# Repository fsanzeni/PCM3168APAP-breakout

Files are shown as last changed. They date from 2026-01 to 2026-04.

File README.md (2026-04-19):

# PCM3168APAP Breakout Board

A breakout board for the Texas Instruments PCM3168APAP audio codec, featuring 6 analog inputs and 8 analog outputs with high-quality buffering and filtering circuitry.
| PCB Front | PCB Back |
|---|---|
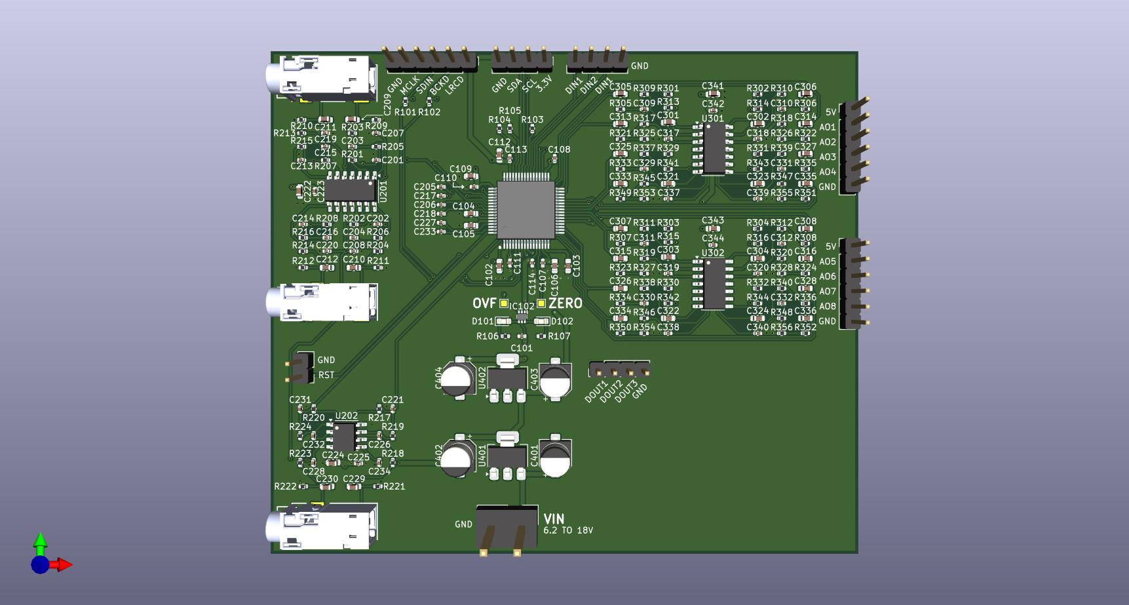
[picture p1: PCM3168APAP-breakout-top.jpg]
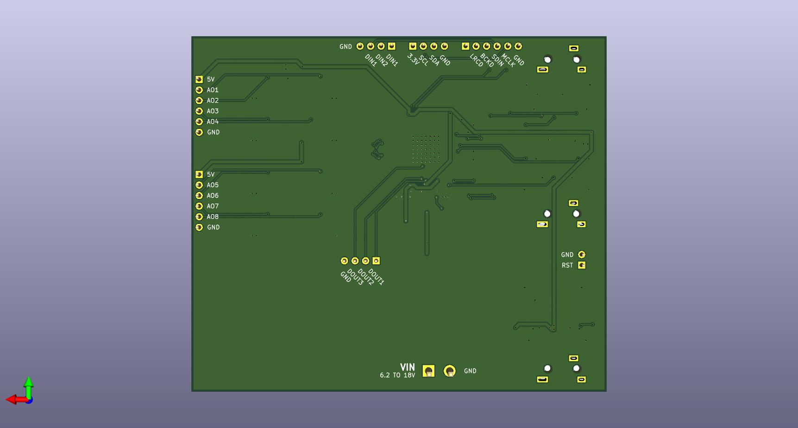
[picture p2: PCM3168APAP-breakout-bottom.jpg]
|  |  |

## Overview

This evaluation board is based on the [TI TIDA-00609](https://www.ti.com/tool/TIDA-00609) reference design and provides a complete interface to the [PCM3168APAP](https://www.ti.com/product/PCM3168A/part-details/PCM3168APAP) - a 24-bit, 96kHz/192kHz, 6-in/8-out audio codec. The board includes analog input buffering with anti-aliasing filters, differential-to-single-ended output conversion, and integrated power regulation (via LDOs for 5v and 3.3v).

## Features

### Audio Codec
- **ADC**: 6-channel, 24-bit delta-sigma ADC with 107 dB dynamic range (differential), 104 dB (single-ended)
- **DAC**: 8-channel, 24-bit delta-sigma DAC with 112 dB dynamic range and differential 8V peak-to-peak outputs
- Sampling rates: 8 kHz to 192 kHz (ADC up to 96 kHz, DAC up to 192 kHz)
- Supports I²S, left-justified, right-justified, DSP, and TDM audio formats

### Analog Signal Path

#### Inputs (6 channels)
- 3.5mm TRS jack connectors for each stereo input pair
- Buffer and anti-aliasing low-pass filter based on [OPA4134](https://www.ti.com/product/OPA4134)/[OPA2134](https://www.ti.com/product/OPA2134) op-amps
- Configured for 2V RMS input, 0.5x gain, -3dB at 48 kHz 
- Output: 1V RMS to ADC
- Common-mode reference voltage (VCOMAD) generation

#### Outputs (8 channels)
- Two 6-pin headers providing 4 channels each
- Post-LPF and differential-to-single-ended conversion using OPA4134 op-amps
- Configured for 4V peak-to-peak DAC output, 0.747x gain, -3dB at 53 kHz
- Output: 2V RMS single-ended

### Digital Interface
- **I²S/Audio** (6-pin header): MCLK, BCK_ADC, LRCK_ADC, BCK_DAC, LRCK_DAC, and ground
- **I²C** (4-pin header): SDA, SCL, 3.3V, and ground
- **Digital Input** (4-pin header): DIN2, DIN3, SDIN (DIN1), and ground
- **Digital Output** (4-pin header): DOUT1, DOUT2, DOUT3, and ground
- **Reset** (2-pin header): Active-low reset with buffer IC ([SN74LVC2G34](https://www.ti.com/product/SN74LVC2G34))

### Configuration
- I²C mode (MODE pin tied to GND)
- I²C device address: 0x88
- Test points for ZERO and OVERFLOW flags
- Status LEDs: Green (ZERO), Yellow (OVERFLOW)

### Power Supply
- Input voltage: 6.2V to 18V
- Dual linear regulators (AMS1117):
  - 5V output for analog circuitry
  - 3.3V output for digital logic
- Comprehensive decoupling throughout

## BOM Highlights

### Key Components
- **IC101**: PCM3168APAP (HTQFP-64 package)
- **IC102**: SN74LVC2G34DRLR (dual buffer for reset/LEDs)
- **U201-U202, U301-U302**: OPA4134UA/OPA2134 (audio op-amps)
- **U401-U402**: AMS1117-5.0 and AMS1117-3.3 (linear regulators)

### Connectors
- J101: 6-pin I²S header
- J102: 4-pin I²C header
- J103-J104: 4-pin DIN/DOUT headers
- J201-J203: 3.5mm TRS analog input jacks
- J301-J302: 6-pin analog output headers
- J401: 2-pin power input

## Usage Notes

- Ensure proper power supply voltage range (6.2V minimum to avoid dropout on regulators) 
- The board is configured for I²C control by default
- All analog inputs accept balanced TRS connections or can be used with unbalanced sources
- Output headers provide differential pairs that have been converted to single-ended signals 

## License

[MIT License](./LICENSE)

## Revision History

- **v0.1** (2026-01-13): Initial release

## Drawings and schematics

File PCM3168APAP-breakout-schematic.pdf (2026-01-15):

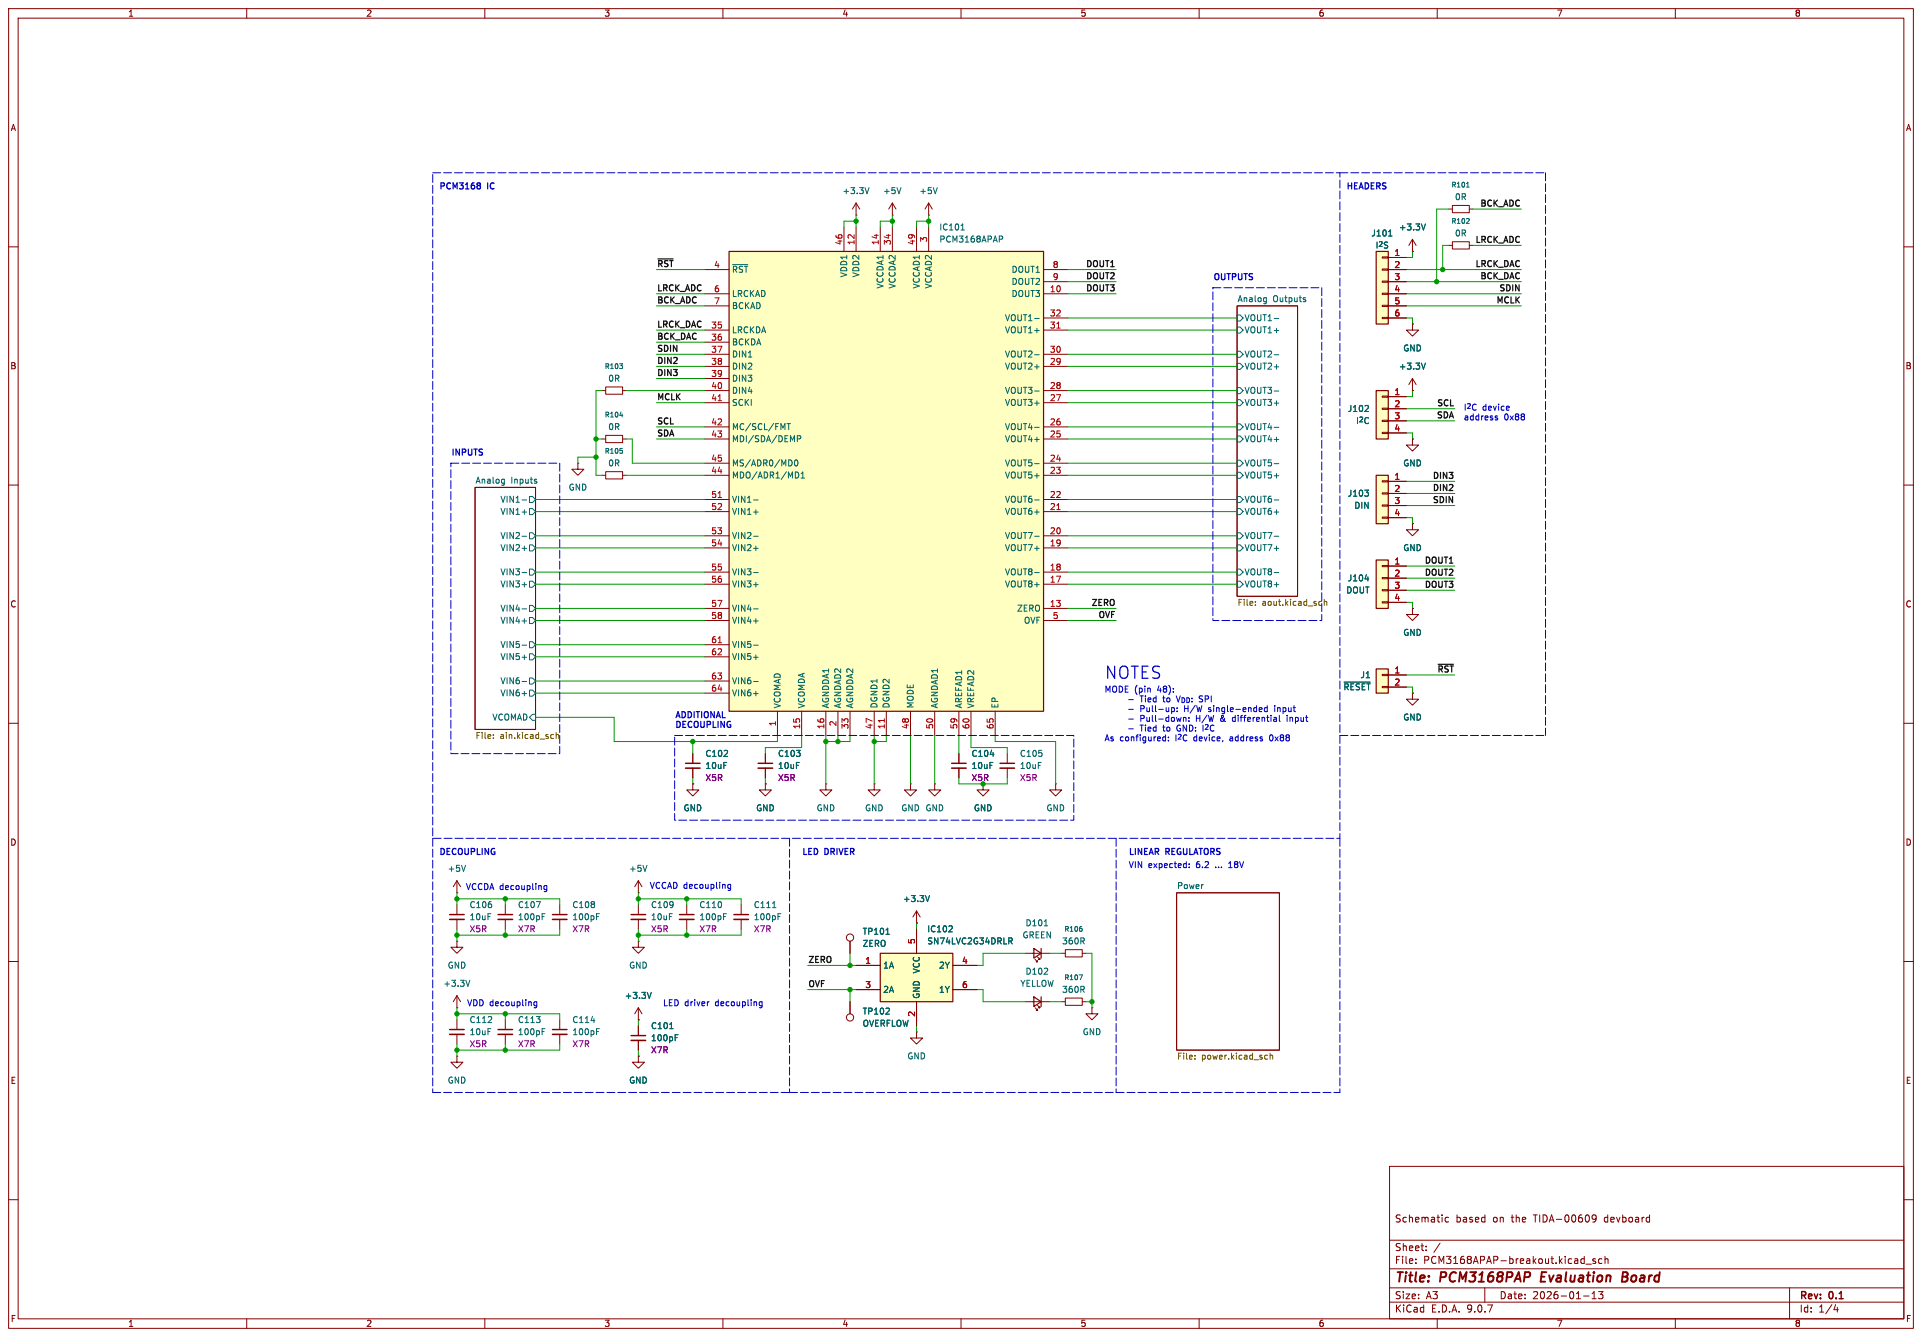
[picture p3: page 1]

VOUT1+ VOUT1- VOUT2+ VOUT2- VOUT3+ VOUT3- VOUT4+ VOUT4- VOUT5+ VOUT5- VOUT6+ VOUT6- VOUT7+ VOUT7- VOUT8+ VOUT8- Analog Outputs File: aout.kicad_sch Power File: power.kicad_sch GND GND

SDIN
VIN1+ VIN1- VIN2+ VIN2- VIN3+ VIN3- VIN4+ VIN4- VIN5+ VIN5- VIN6+ VIN6- Analog Inputs File: ain.kicad_sch

Id: 1/4 Title: PCM3168PAP Evaluation Board

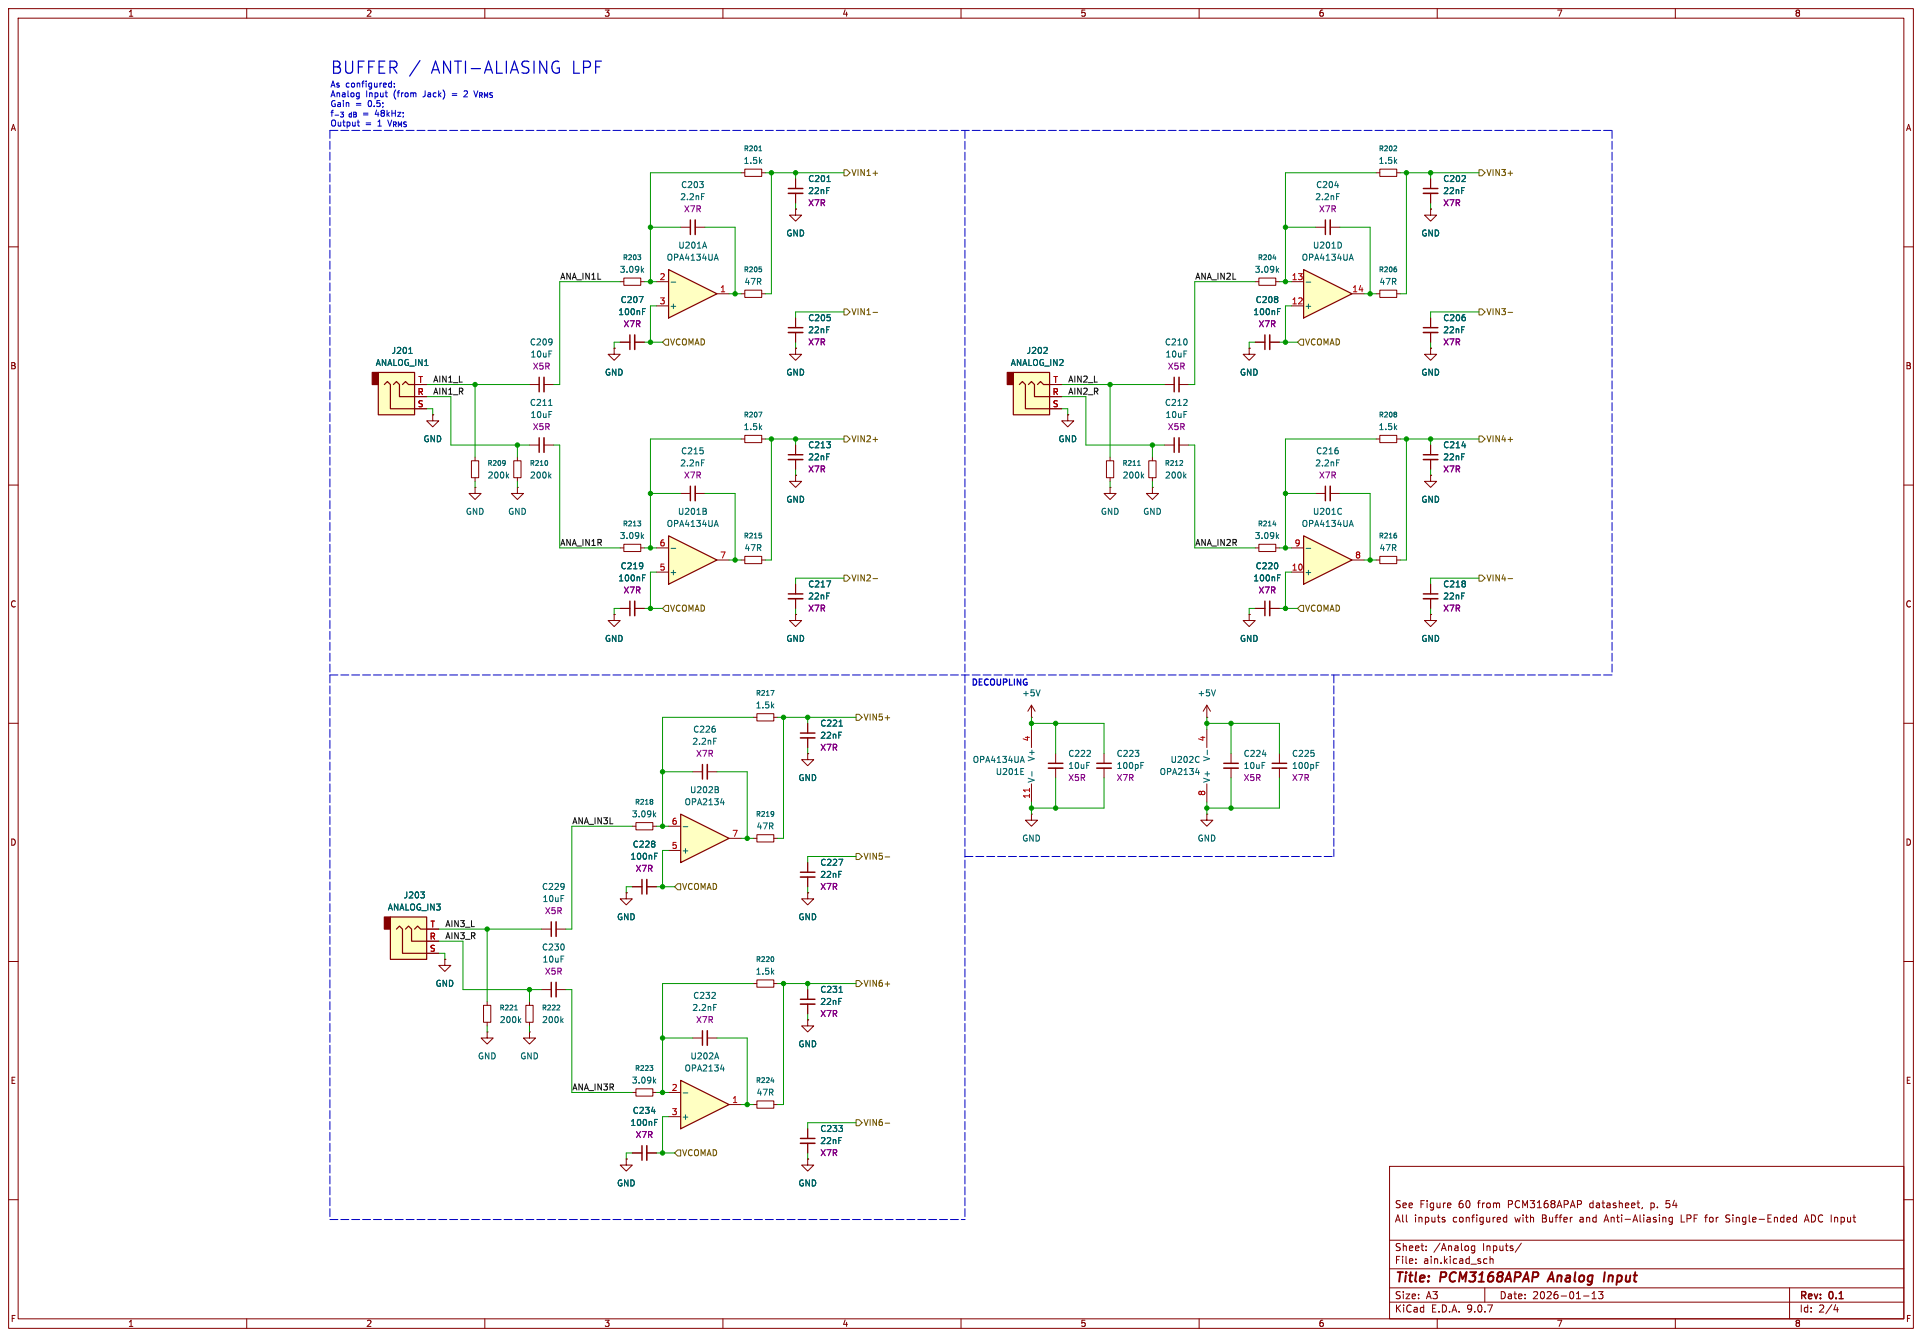
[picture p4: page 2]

BUFFER / ANTI-ALIASING LPF
AIN1_L As configured:
Analog Input (from Jack) = 2 V_{RMS} Gain = 0.5;
1 U201A OPA4134UA C219

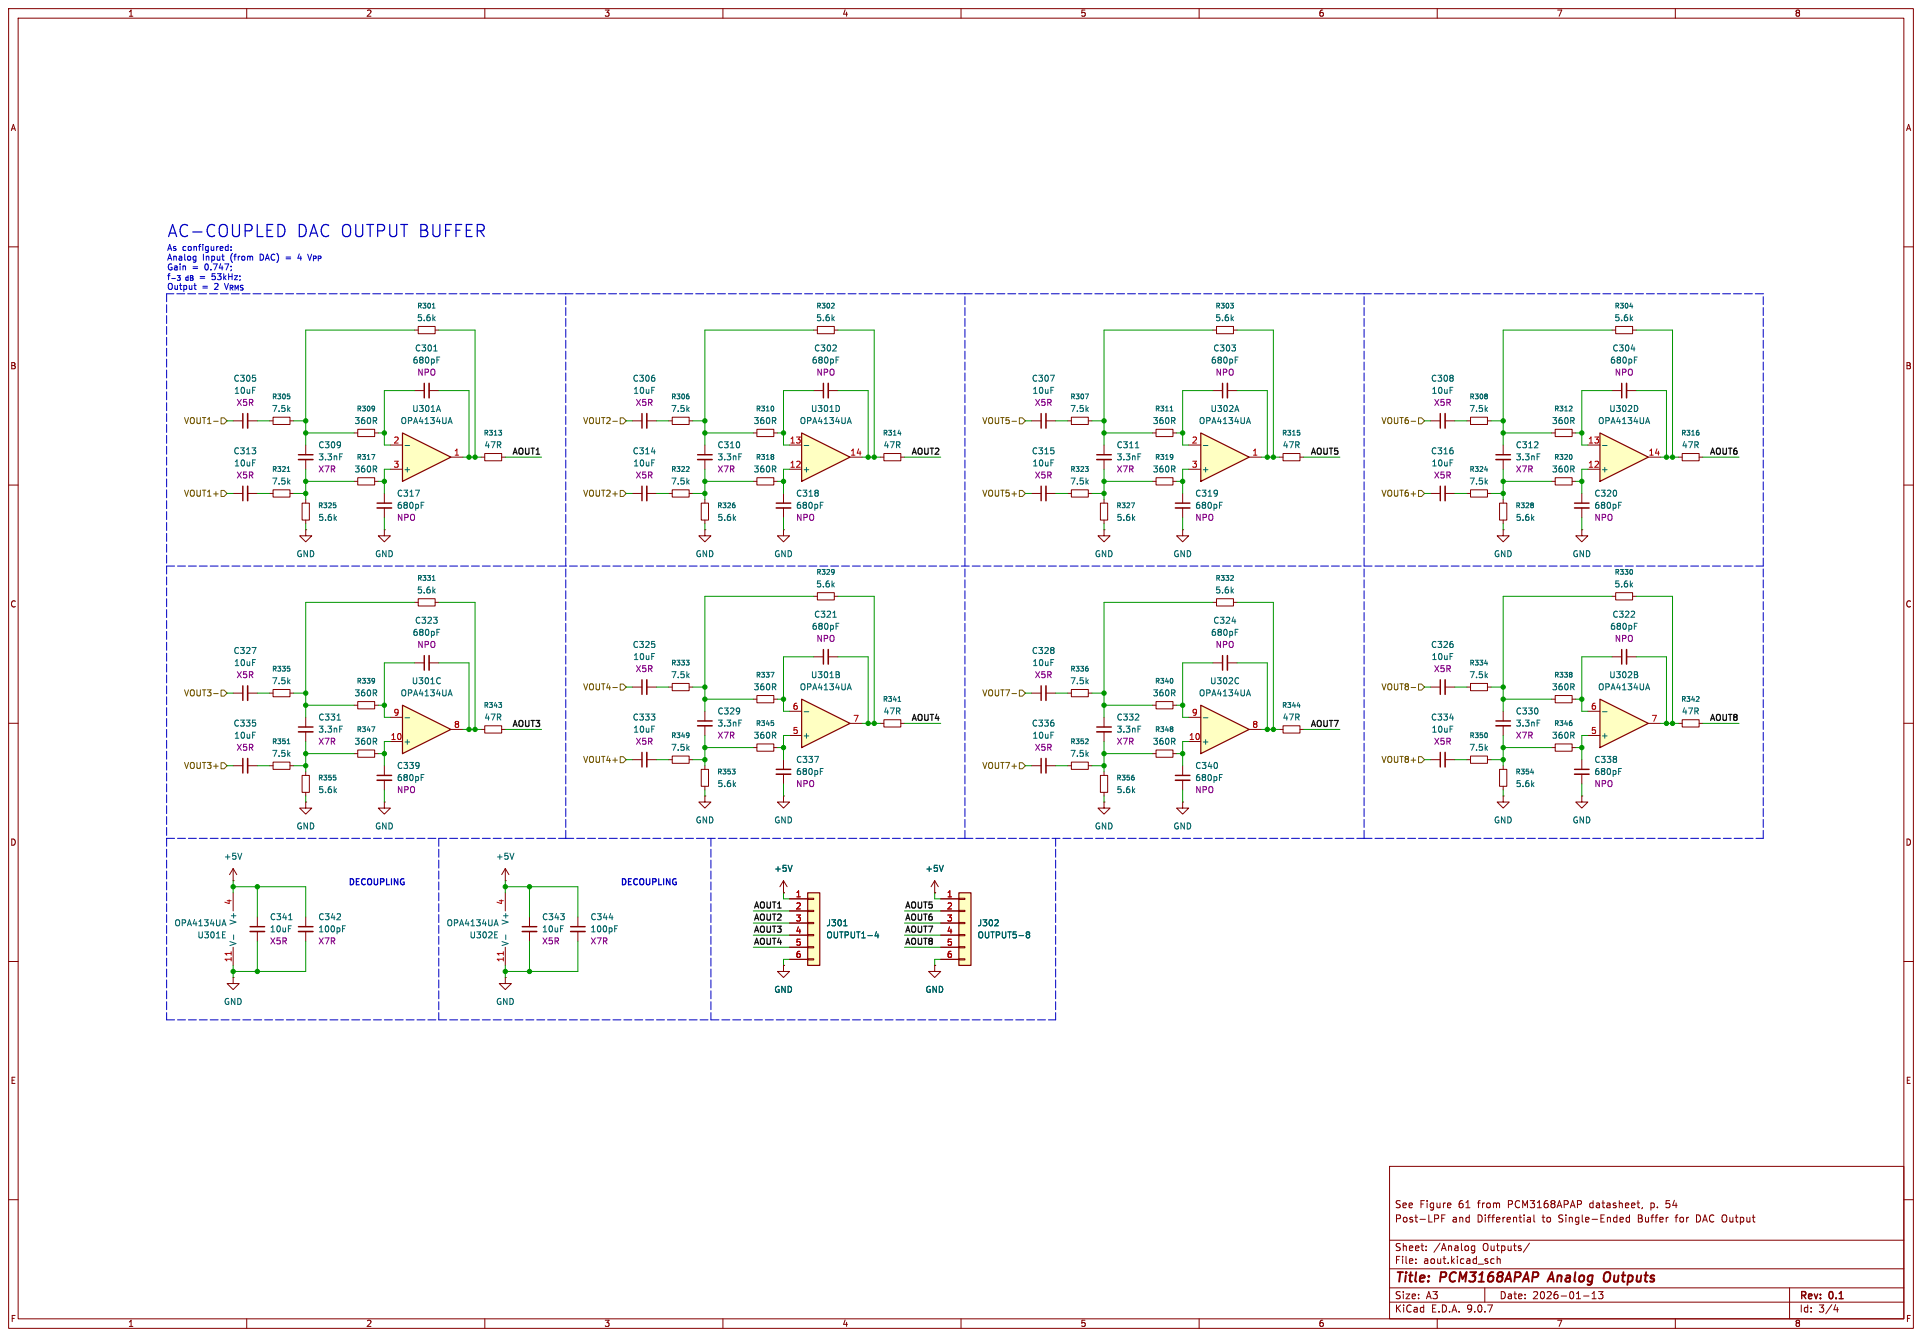
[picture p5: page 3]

As configured:
Analog Input (from DAC) = 4 V_{PP} Gain = 0.747;

Id: 3/4 Title: PCM3168APAP Analog Outputs

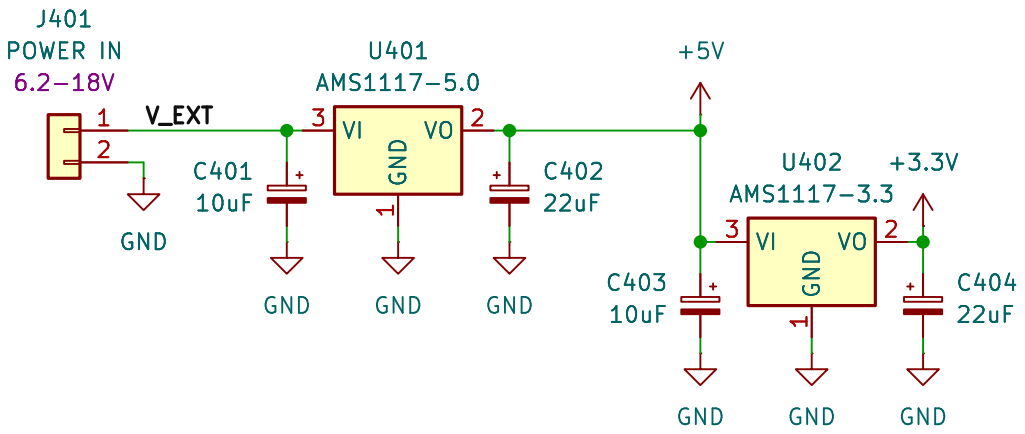
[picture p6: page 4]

Id: 4/4 Title: File: power.kicad_sch Sheet: /Power/

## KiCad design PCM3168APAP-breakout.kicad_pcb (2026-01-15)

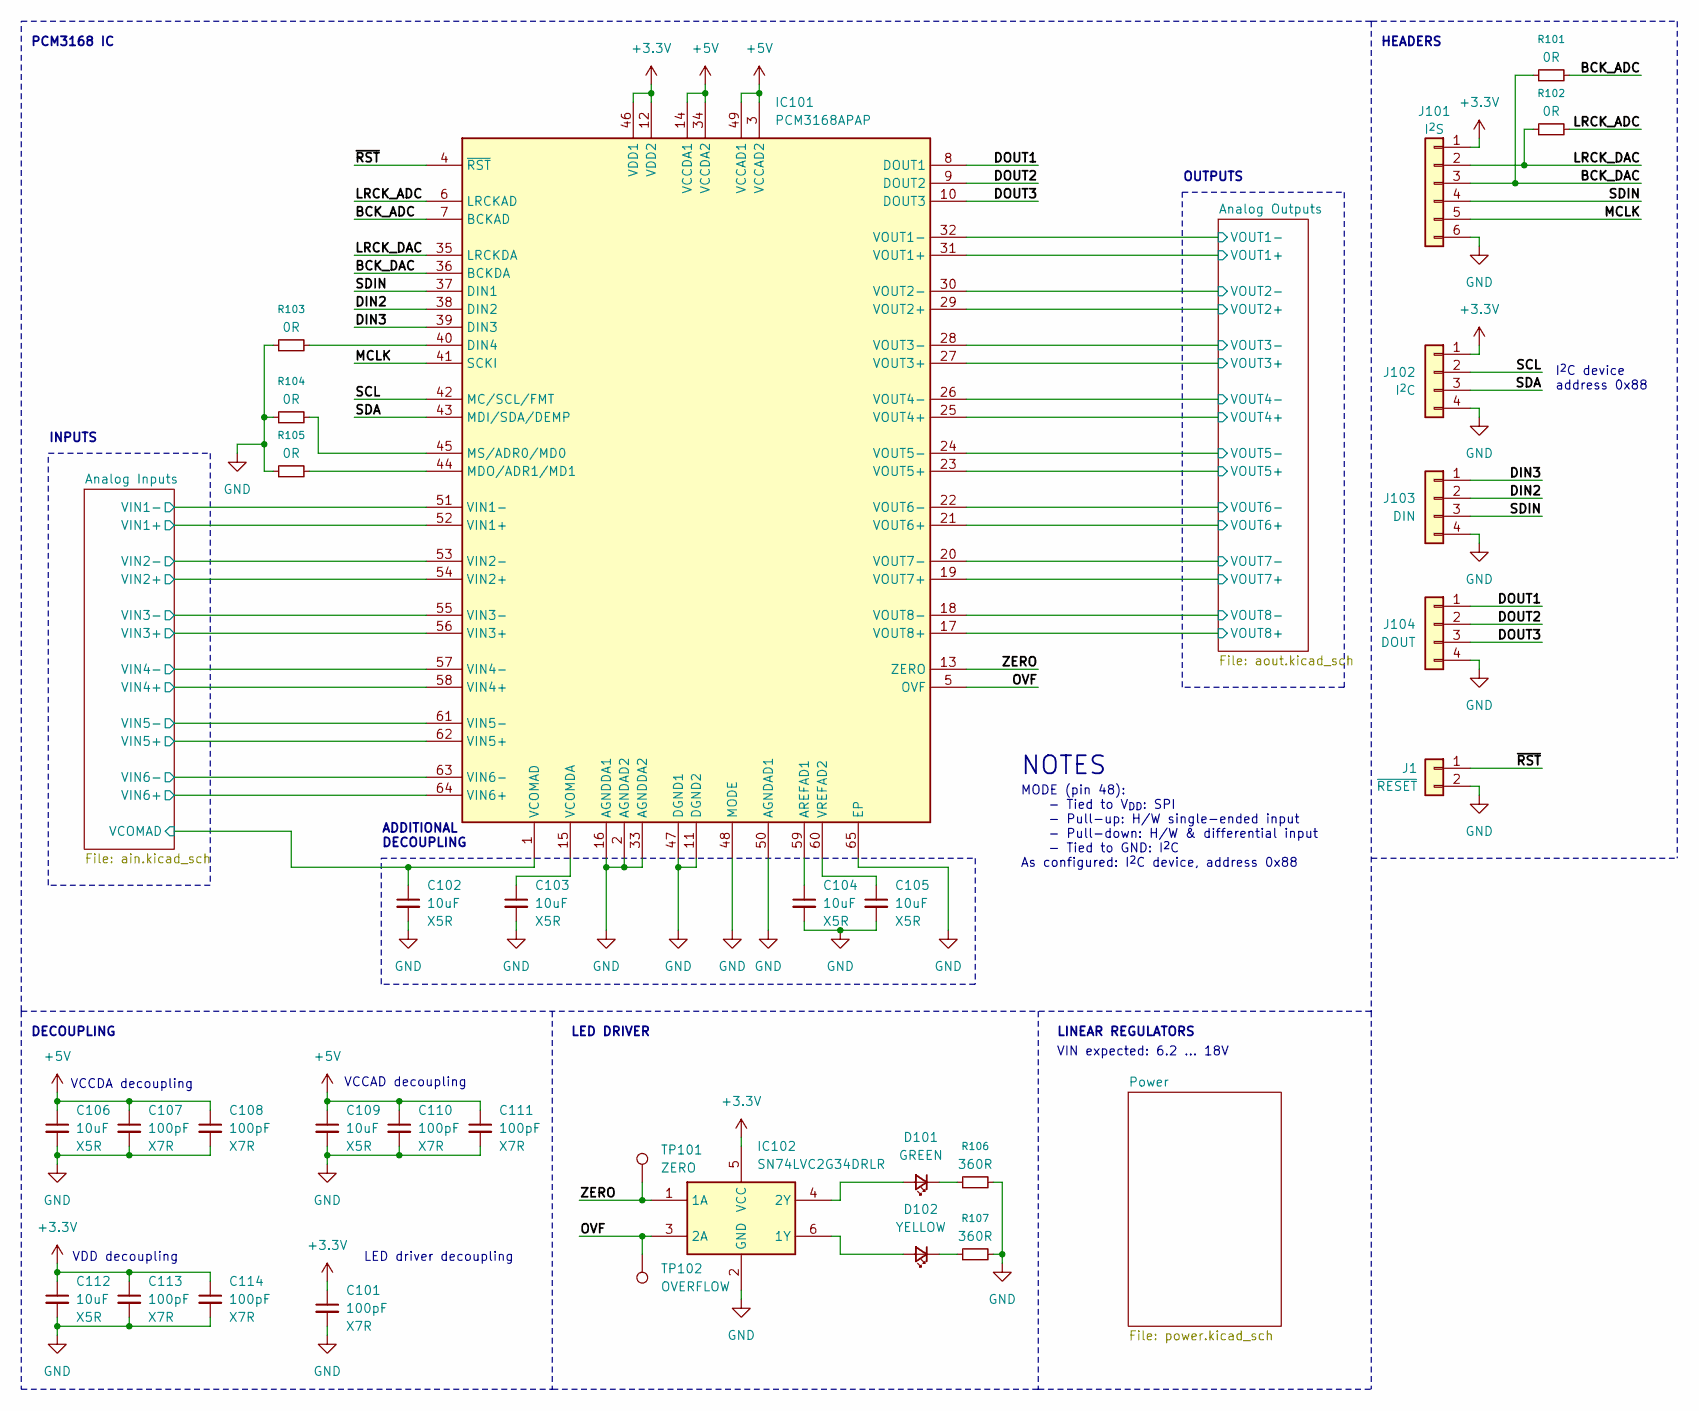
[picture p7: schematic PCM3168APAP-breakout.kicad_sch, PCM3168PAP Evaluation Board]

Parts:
C101, C107, C108, C110, C111, C113, C114: 100pF; C_0402_1005Metric
C102, C103, C104, C105, C106, C109, C112: 10uF; C_0603_1608Metric
D101: GREEN; LED_0603_1608Metric
D102: YELLOW; LED_0603_1608Metric
IC101: PCM3168APAP; QFP50P1200X1200X120-65N; Mouser Part Number 595-PCM3168APAP
IC102: SN74LVC2G34DRLR; SOTFL50P160X60-6N; Mouser Part Number 595-SN74LVC2G34DRLR
J1: ~{RESET}; PinHeader_1x02_P2.54mm_Vertical
J101: I^{2}S; PinHeader_1x06_P2.54mm_Vertical
J102: I^{2}C; PinHeader_1x04_P2.54mm_Vertical
J103: DIN; PinHeader_1x04_P2.54mm_Vertical
J104: DOUT; PinHeader_1x04_P2.54mm_Vertical
R101, R102, R103, R104, R105: 0R; R_0402_1005Metric
R106, R107: 360R; R_0402_1005Metric
TP101: ZERO; TestPoint_Pad_1.0x1.0mm
TP102: OVERFLOW; TestPoint_Pad_1.0x1.0mm

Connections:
+3.3V: C101.1, C112.1, C113.1, C114.1, IC101.12 (VDD2), IC101.46 (VDD1), IC102.5 (VCC), J101.1, J102.1; also elsewhere on the board
+5V: C106.1, C107.1, C108.1, C109.1, C110.1, C111.1, IC101.3 (VCCAD2), IC101.14 (VCCDA1), IC101.34 (VCCDA2), IC101.49 (VCCAD1); also elsewhere on the board
/Analog Inputs/VCOMAD: C102.1, IC101.1 (VCOMAD); also elsewhere on the board
/Analog Inputs/VIN1+: IC101.52 (VIN1+); also elsewhere on the board
/Analog Inputs/VIN1-: IC101.51 (VIN1-); also elsewhere on the board
/Analog Inputs/VIN2+: IC101.54 (VIN2+); also elsewhere on the board
/Analog Inputs/VIN2-: IC101.53 (VIN2-); also elsewhere on the board
/Analog Inputs/VIN3+: IC101.56 (VIN3+); also elsewhere on the board
/Analog Inputs/VIN3-: IC101.55 (VIN3-); also elsewhere on the board
/Analog Inputs/VIN4+: IC101.58 (VIN4+); also elsewhere on the board
/Analog Inputs/VIN4-: IC101.57 (VIN4-); also elsewhere on the board
/Analog Inputs/VIN5+: IC101.62 (VIN5+); also elsewhere on the board
/Analog Inputs/VIN5-: IC101.61 (VIN5-); also elsewhere on the board
/Analog Inputs/VIN6+: IC101.64 (VIN6+); also elsewhere on the board
/Analog Inputs/VIN6-: IC101.63 (VIN6-); also elsewhere on the board
/Analog Outputs/VOUT1+: IC101.31 (VOUT1+); also elsewhere on the board
/Analog Outputs/VOUT1-: IC101.32 (VOUT1-); also elsewhere on the board
/Analog Outputs/VOUT2+: IC101.29 (VOUT2+); also elsewhere on the board
/Analog Outputs/VOUT2-: IC101.30 (VOUT2-); also elsewhere on the board
/Analog Outputs/VOUT3+: IC101.27 (VOUT3+); also elsewhere on the board
/Analog Outputs/VOUT3-: IC101.28 (VOUT3-); also elsewhere on the board
/Analog Outputs/VOUT4+: IC101.25 (VOUT4+); also elsewhere on the board
/Analog Outputs/VOUT4-: IC101.26 (VOUT4-); also elsewhere on the board
/Analog Outputs/VOUT5+: IC101.23 (VOUT5+); also elsewhere on the board
/Analog Outputs/VOUT5-: IC101.24 (VOUT5-); also elsewhere on the board
/Analog Outputs/VOUT6+: IC101.21 (VOUT6+); also elsewhere on the board
/Analog Outputs/VOUT6-: IC101.22 (VOUT6-); also elsewhere on the board
/Analog Outputs/VOUT7+: IC101.19 (VOUT7+); also elsewhere on the board
/Analog Outputs/VOUT7-: IC101.20 (VOUT7-); also elsewhere on the board
/Analog Outputs/VOUT8+: IC101.17 (VOUT8+); also elsewhere on the board
/Analog Outputs/VOUT8-: IC101.18 (VOUT8-); also elsewhere on the board
/BCK_ADC: IC101.7 (BCKAD), R101.2
/BCK_DAC: IC101.36 (BCKDA), J101.3, R101.1
/DIN2: IC101.38 (DIN2), J103.2
/DIN3: IC101.39 (DIN3), J103.1
/DOUT1: IC101.8 (DOUT1), J104.1
/DOUT2: IC101.9 (DOUT2), J104.2
/DOUT3: IC101.10 (DOUT3), J104.3
/LRCK_ADC: IC101.6 (LRCKAD), R102.2
/LRCK_DAC: IC101.35 (LRCKDA), J101.2, R102.1
/MCLK: IC101.41 (SCKI), J101.5
/OVF: IC101.5 (OVF), IC102.3 (2A), TP102.1
/SCL: IC101.42 (MC/SCL/FMT), J102.2
/SDA: IC101.43 (MDI/SDA/DEMP), J102.3
/SDIN: IC101.37 (DIN1), J101.4, J103.3
/ZERO: IC101.13 (ZERO), IC102.1 (1A), TP101.1
/~RST: IC101.4 (~RST), J1.1
GND: C101.2, C102.2, C103.2, C104.2, C105.2, C106.2, C107.2, C108.2, C109.2, C110.2, C111.2, C112.2, C113.2, C114.2, IC101.2 (AGNDAD2), IC101.11 (DGND2), IC101.16 (AGNDDA1), IC101.33 (AGNDDA2), IC101.47 (DGND1), IC101.48 (MODE), IC101.50 (AGNDAD1), IC101.65 (EP), IC102.2 (GND), J1.2, J101.6, J102.4, J103.4, J104.4, R103.1, R104.1, R105.1, R106.2, R107.2; also elsewhere on the board
unnamed: D101.2 (A), IC102.4 (2Y)
unnamed: D101.1 (K), R106.1
unnamed: D102.2 (A), IC102.6 (1Y)
unnamed: D102.1 (K), R107.1
unnamed: C104.1, IC101.59 (AREFAD1)
unnamed: IC101.40 (DIN4), R103.2
unnamed: IC101.44 (MDO/ADR1/MD1), R105.2
unnamed: IC101.45 (MS/ADR0/MD0), R104.2
unnamed: C103.1, IC101.15 (VCOMDA)
unnamed: C105.1, IC101.60 (VREFAD2)

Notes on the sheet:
LED DRIVER
I^{2}C device address 0x88
DECOUPLING
PCM3168 IC
VCCAD decoupling
ADDITIONAL DECOUPLING
OUTPUTS
VDD decoupling
VCCDA decoupling
VIN expected: 6.2 ... 18V
LED driver decoupling
INPUTS
MODE (pin 48): - Tied to V_{DD}: SPI - Pull-up: H/W single-ended input - Pull-down: H/W & differential input - Tied to GND: I^{2}C As configured: I^{2}C device, address 0x88
NOTES
HEADERS
LINEAR REGULATORS

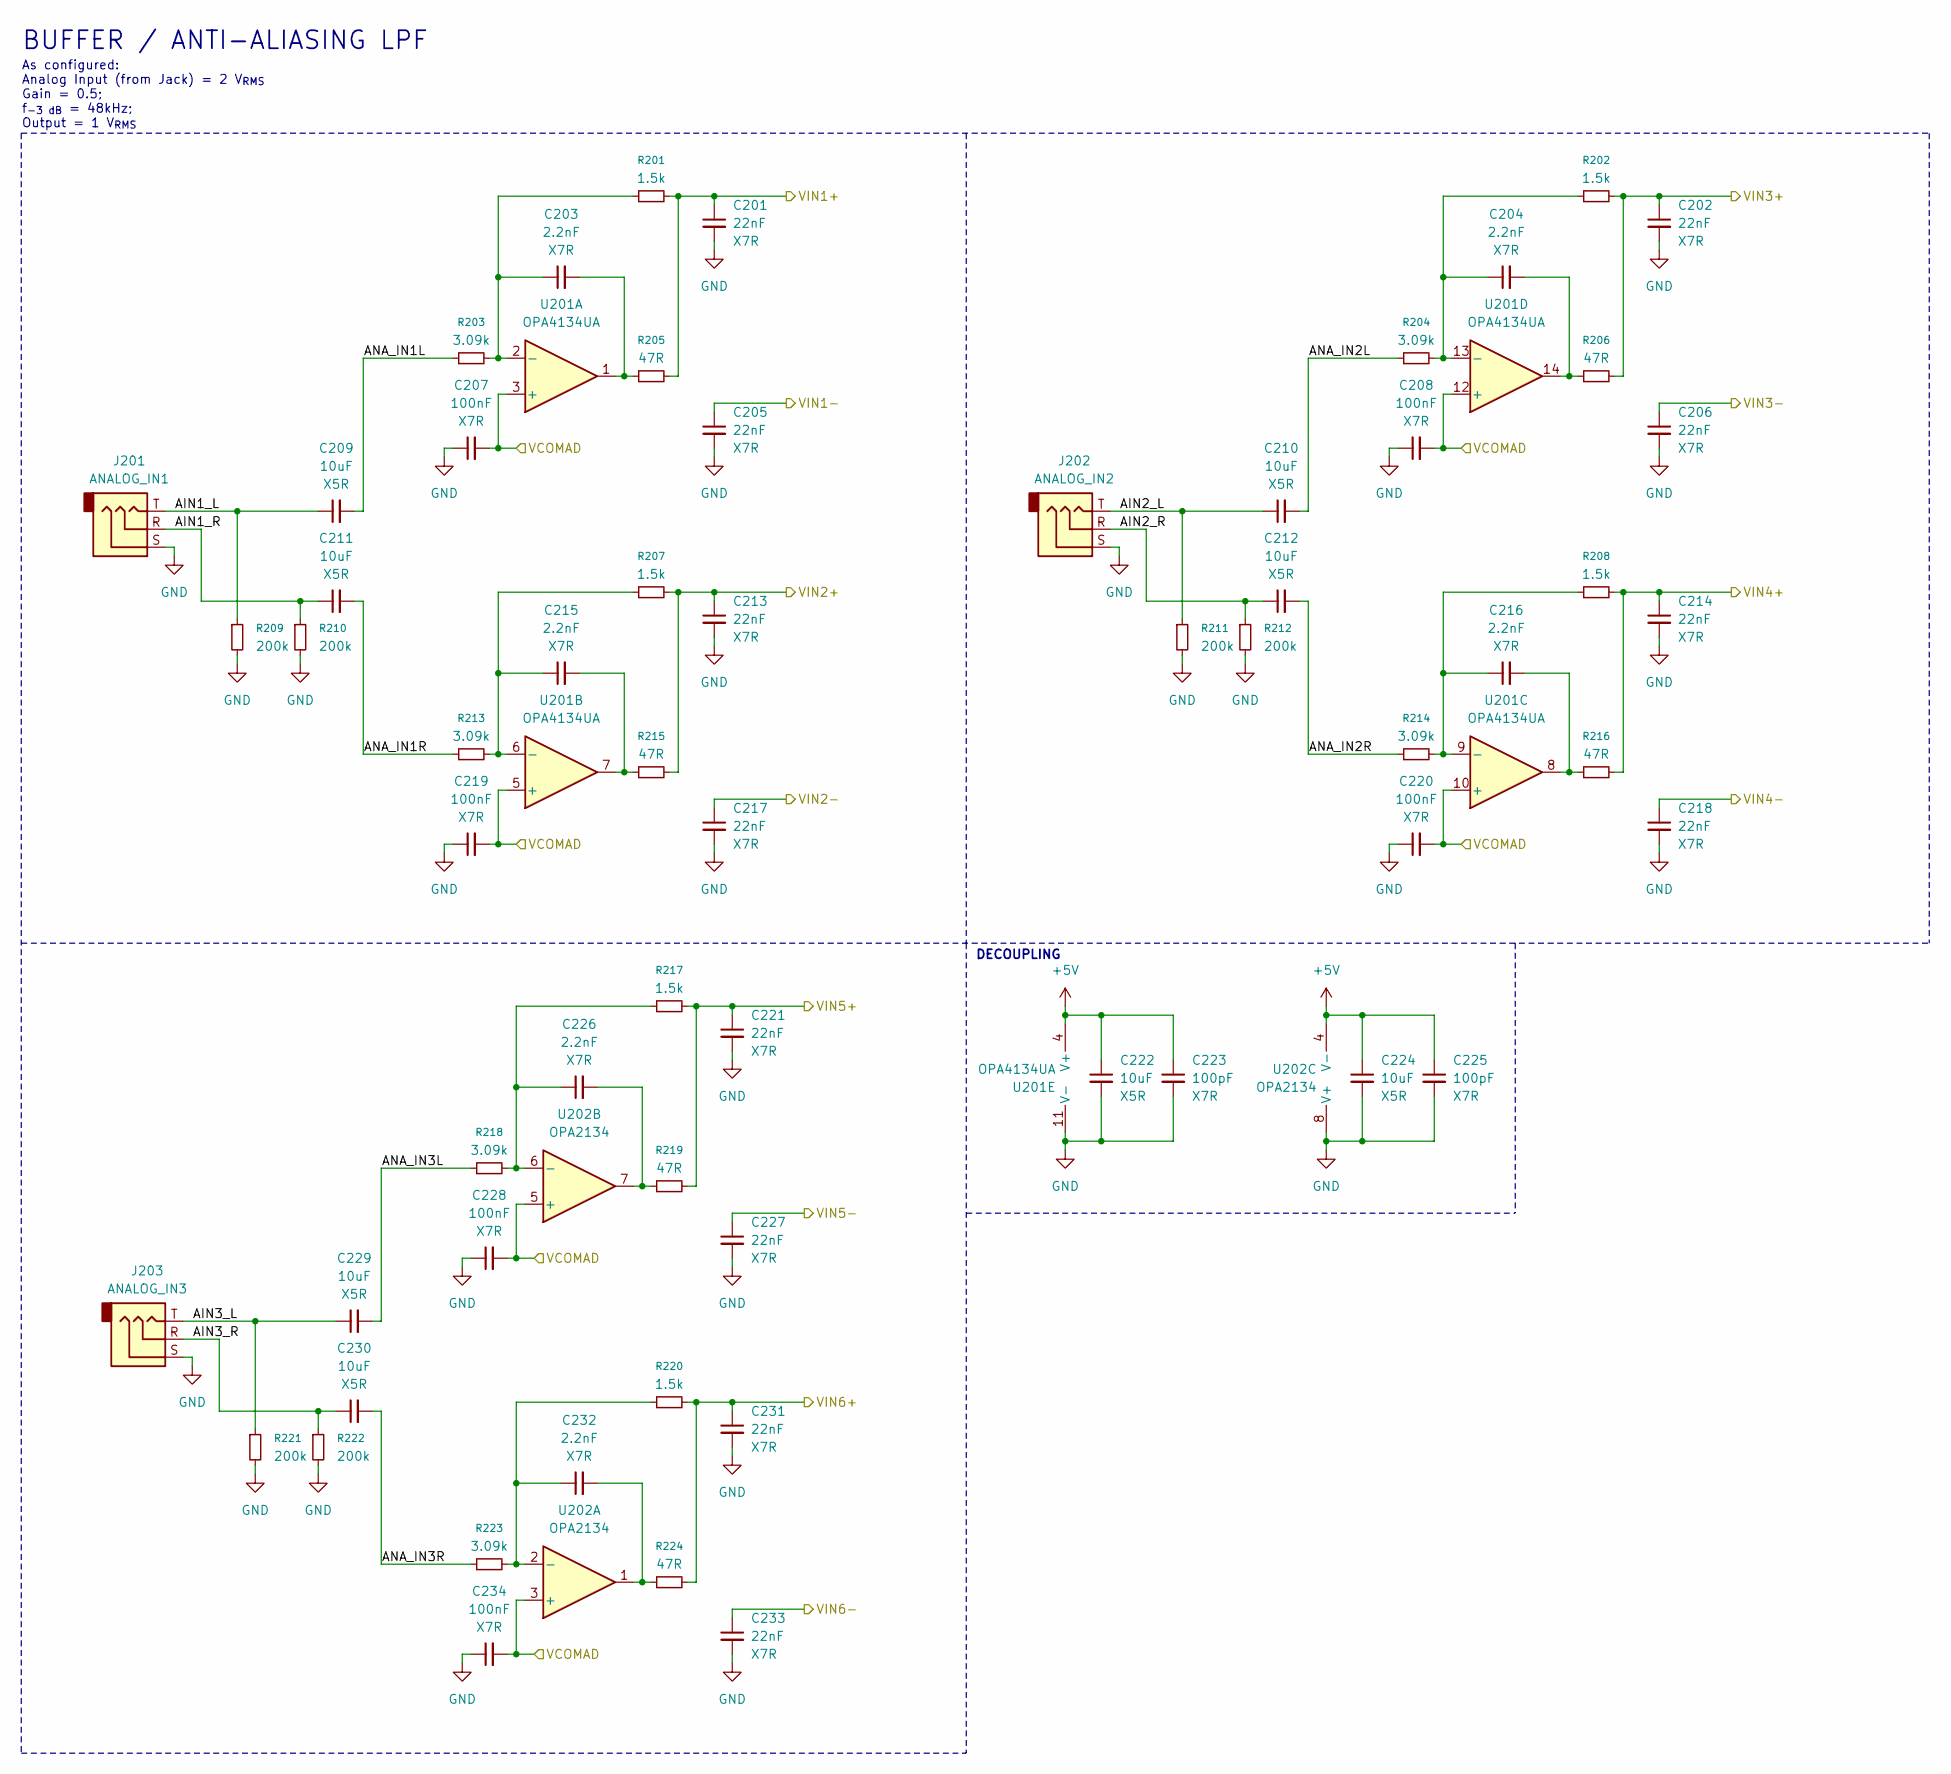
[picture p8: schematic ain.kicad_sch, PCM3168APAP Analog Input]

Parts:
C201, C202, C205, C206, C213, C214, C217, C218, C221, C227, C231, C233: 22nF; C_0402_1005Metric
C203, C204, C215, C216, C226, C232: 2.2nF; C_0402_1005Metric
C207, C208, C219, C220, C228, C234: 100nF; C_0402_1005Metric
C209, C210, C211, C212, C222, C224, C229, C230: 10uF; C_0603_1608Metric
C223, C225: 100pF; C_0402_1005Metric
J201: ANALOG_IN1; SJ335083ATR
J202: ANALOG_IN2; SJ335083ATR
J203: ANALOG_IN3; SJ335083ATR
R201, R202, R207, R208, R217, R220: 1.5k; R_0402_1005Metric
R203, R204, R213, R214, R218, R223: 3.09k; R_0402_1005Metric
R205, R206, R215, R216, R219, R224: 47R; R_0402_1005Metric
R209, R210, R211, R212, R221, R222: 200k; R_0402_1005Metric
U201: OPA4134UA; SOIC-14_3.9x8.7mm_P1.27mm
U202: OPA2134; SOIC-8_3.9x4.9mm_P1.27mm

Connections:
+5V: C222.1, C223.1, C224.1, C225.1, U201.4 (V+), U202.4 (V-); also elsewhere on the board
/Analog Inputs/AIN1_L: C209.1, J201.T, R209.1
/Analog Inputs/AIN1_R: C211.1, J201.R, R210.1
/Analog Inputs/AIN2_L: C210.1, J202.T, R211.1
/Analog Inputs/AIN2_R: C212.1, J202.R, R212.1
/Analog Inputs/AIN3_L: C229.1, J203.T, R221.1
/Analog Inputs/AIN3_R: C230.1, J203.R, R222.1
/Analog Inputs/ANA_IN1L: C209.2, R203.1
/Analog Inputs/ANA_IN1R: C211.2, R213.1
/Analog Inputs/ANA_IN2L: C210.2, R204.1
/Analog Inputs/ANA_IN2R: C212.2, R214.1
/Analog Inputs/ANA_IN3L: C229.2, R218.1
/Analog Inputs/ANA_IN3R: C230.2, R223.1
/Analog Inputs/VCOMAD: C207.2, C208.2, C219.2, C220.2, C228.2, C234.2, U201.3 (+), U201.5 (+), U201.10 (+), U201.12 (+), U202.3 (+), U202.5 (+); also elsewhere on the board
/Analog Inputs/VIN1+: C201.1, R201.2, R205.2; also elsewhere on the board
/Analog Inputs/VIN1-: C205.1; also elsewhere on the board
/Analog Inputs/VIN2+: C213.1, R207.2, R215.2; also elsewhere on the board
/Analog Inputs/VIN2-: C217.1; also elsewhere on the board
/Analog Inputs/VIN3+: C202.1, R202.2, R206.2; also elsewhere on the board
/Analog Inputs/VIN3-: C206.1; also elsewhere on the board
/Analog Inputs/VIN4+: C214.1, R208.2, R216.2; also elsewhere on the board
/Analog Inputs/VIN4-: C218.1; also elsewhere on the board
/Analog Inputs/VIN5+: C221.1, R217.2, R219.2; also elsewhere on the board
/Analog Inputs/VIN5-: C227.1; also elsewhere on the board
/Analog Inputs/VIN6+: C231.1, R220.2, R224.2; also elsewhere on the board
/Analog Inputs/VIN6-: C233.1; also elsewhere on the board
GND: C201.2, C202.2, C205.2, C206.2, C207.1, C208.1, C213.2, C214.2, C217.2, C218.2, C219.1, C220.1, C221.2, C222.2, C223.2, C224.2, C225.2, C227.2, C228.1, C231.2, C233.2, C234.1, J201.S, J202.S, J203.S, R209.2, R210.2, R211.2, R212.2, R221.2, R222.2, U201.11 (V-), U202.8 (V+); also elsewhere on the board
unnamed: C203.2, R205.1, U201.1
unnamed: C204.2, R206.1, U201.14
unnamed: C215.2, R215.1, U201.7
unnamed: C216.2, R216.1, U201.8
unnamed: C226.2, R219.1, U202.7
unnamed: C232.2, R224.1, U202.1
unnamed: C203.1, R201.1, R203.2, U201.2 (-)
unnamed: C215.1, R207.1, R213.2, U201.6 (-)
unnamed: C216.1, R208.1, R214.2, U201.9 (-)
unnamed: C204.1, R202.1, R204.2, U201.13 (-)
unnamed: C232.1, R220.1, R223.2, U202.2 (-)
unnamed: C226.1, R217.1, R218.2, U202.6 (-)

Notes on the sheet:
DECOUPLING
BUFFER / ANTI-ALIASING LPF
As configured: Analog Input (from Jack) = 2 V_{RMS} Gain = 0.5; f_{-3 dB} = 48kHz; Output = 1 V_{RMS}

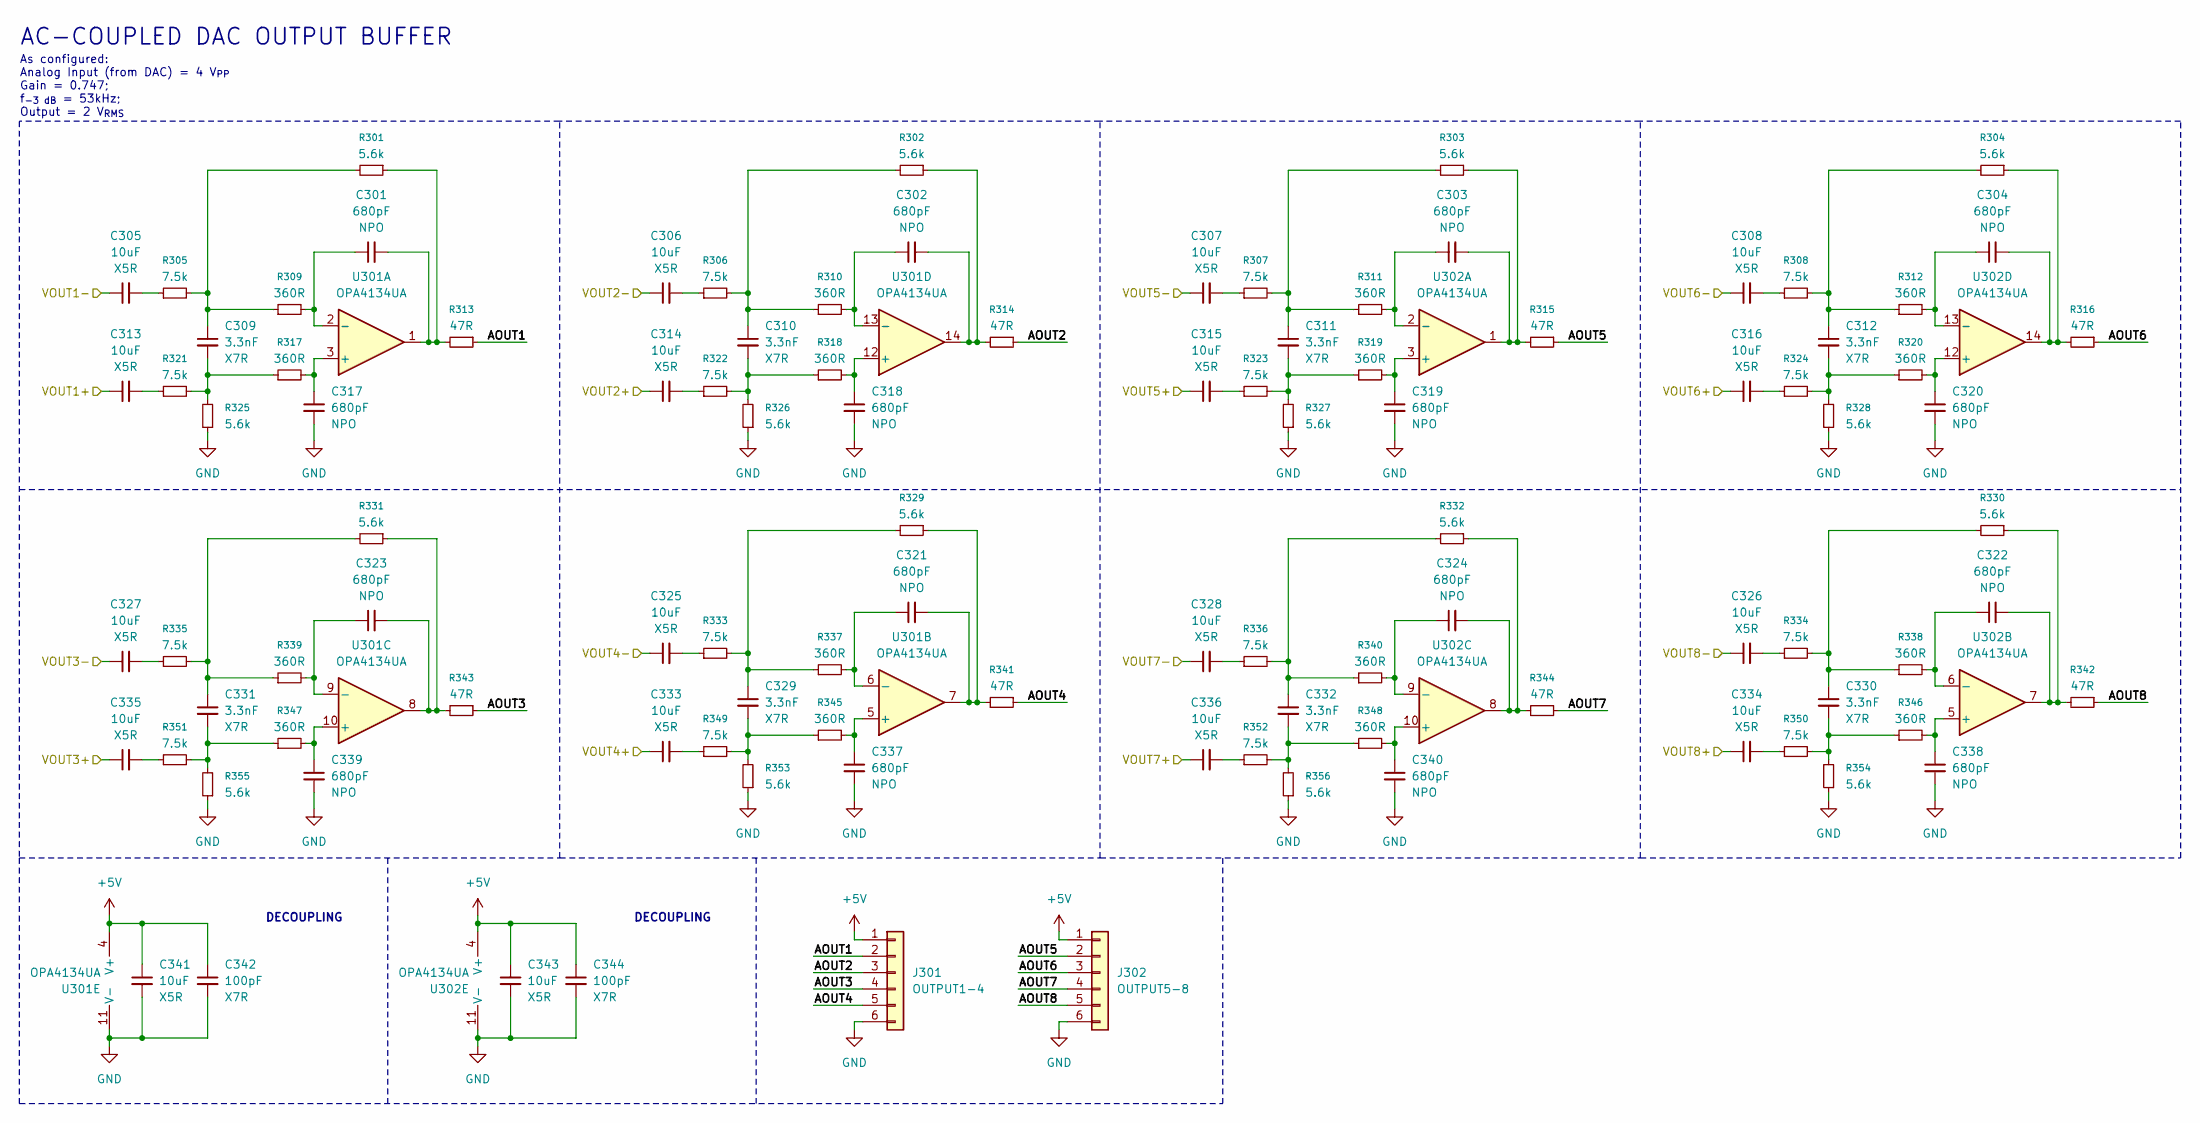
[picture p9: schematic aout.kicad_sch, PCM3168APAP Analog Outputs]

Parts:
C301, C302, C303, C304, C321, C322, C323, C324: 680pF; C_0603_1608Metric
C305, C306, C307, C308, C313, C314, C315, C316, C325, C326, C327, C328, C333, C334, C335, C336, C341, C343: 10uF; C_0603_1608Metric
C309, C310, C311, C312, C329, C330, C331, C332: 3.3nF; C_0402_1005Metric
C317, C318, C319, C320, C337, C338, C339, C340: 680pF; C_0402_1005Metric
C342, C344: 100pF; C_0402_1005Metric
J301: OUTPUT1-4; PinHeader_1x06_P2.54mm_Vertical
J302: OUTPUT5-8; PinHeader_1x06_P2.54mm_Vertical
R301, R302, R303, R304, R325, R326, R327, R328, R329, R330, R331, R332, R353, R354, R355, R356: 5.6k; R_0402_1005Metric
R305, R306, R307, R308, R321, R322, R323, R324, R333, R334, R335, R336, R349, R350, R351, R352: 7.5k; R_0402_1005Metric
R309, R310, R311, R312, R317, R318, R319, R320, R337, R338, R339, R340, R345, R346, R347, R348: 360R; R_0402_1005Metric
R313, R314, R315, R316, R341, R342, R343, R344: 47R; R_0402_1005Metric
U301, U302: OPA4134UA; SOIC-14_3.9x8.7mm_P1.27mm

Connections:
+5V: C341.1, C342.1, C343.1, C344.1, J301.1, J302.1, U301.4 (V+), U302.4 (V+); also elsewhere on the board
/Analog Outputs/AOUT1: J301.2, R313.1
/Analog Outputs/AOUT2: J301.3, R314.1
/Analog Outputs/AOUT3: J301.4, R343.1
/Analog Outputs/AOUT4: J301.5, R341.1
/Analog Outputs/AOUT5: J302.2, R315.1
/Analog Outputs/AOUT6: J302.3, R316.1
/Analog Outputs/AOUT7: J302.4, R344.1
/Analog Outputs/AOUT8: J302.5, R342.1
/Analog Outputs/VOUT1+: C313.1; also elsewhere on the board
/Analog Outputs/VOUT1-: C305.1; also elsewhere on the board
/Analog Outputs/VOUT2+: C314.1; also elsewhere on the board
/Analog Outputs/VOUT2-: C306.1; also elsewhere on the board
/Analog Outputs/VOUT3+: C335.1; also elsewhere on the board
/Analog Outputs/VOUT3-: C327.1; also elsewhere on the board
/Analog Outputs/VOUT4+: C333.1; also elsewhere on the board
/Analog Outputs/VOUT4-: C325.1; also elsewhere on the board
/Analog Outputs/VOUT5+: C315.1; also elsewhere on the board
/Analog Outputs/VOUT5-: C307.1; also elsewhere on the board
/Analog Outputs/VOUT6+: C316.1; also elsewhere on the board
/Analog Outputs/VOUT6-: C308.1; also elsewhere on the board
/Analog Outputs/VOUT7+: C336.1; also elsewhere on the board
/Analog Outputs/VOUT7-: C328.1; also elsewhere on the board
/Analog Outputs/VOUT8+: C334.1; also elsewhere on the board
/Analog Outputs/VOUT8-: C326.1; also elsewhere on the board
GND: C317.2, C318.2, C319.2, C320.2, C337.2, C338.2, C339.2, C340.2, C341.2, C342.2, C343.2, C344.2, J301.6, J302.6, R325.1, R326.1, R327.1, R328.1, R353.1, R354.1, R355.1, R356.1, U301.11 (V-), U302.11 (V-); also elsewhere on the board
unnamed: C301.2, R301.1, R313.2, U301.1
unnamed: C302.2, R302.1, R314.2, U301.14
unnamed: C303.2, R303.1, R315.2, U302.1
unnamed: C304.2, R304.1, R316.2, U302.14
unnamed: C305.2, R305.1
unnamed: C306.2, R306.1
unnamed: C307.2, R307.1
unnamed: C308.2, R308.1
unnamed: C309.1, R301.2, R305.2, R309.1
unnamed: C309.2, R317.1, R321.2, R325.2
unnamed: C310.1, R302.2, R306.2, R310.1
unnamed: C310.2, R318.1, R322.2, R326.2
unnamed: C311.1, R303.2, R307.2, R311.1
unnamed: C311.2, R319.1, R323.2, R327.2
unnamed: C312.1, R304.2, R308.2, R312.1
unnamed: C312.2, R320.1, R324.2, R328.2
unnamed: C313.2, R321.1
unnamed: C314.2, R322.1
unnamed: C315.2, R323.1
unnamed: C316.2, R324.1
unnamed: C321.2, R329.1, R341.2, U301.7
unnamed: C322.2, R330.1, R342.2, U302.7
unnamed: C323.2, R331.1, R343.2, U301.8
unnamed: C324.2, R332.1, R344.2, U302.8
unnamed: C325.2, R333.1
unnamed: C326.2, R334.1
unnamed: C327.2, R335.1
unnamed: C328.2, R336.1
unnamed: C329.1, R329.2, R333.2, R337.1
unnamed: C329.2, R345.1, R349.2, R353.2
unnamed: C330.1, R330.2, R334.2, R338.1
unnamed: C330.2, R346.1, R350.2, R354.2
unnamed: C331.1, R331.2, R335.2, R339.1
unnamed: C331.2, R347.1, R351.2, R355.2
unnamed: C332.1, R332.2, R336.2, R340.1
unnamed: C332.2, R348.1, R352.2, R356.2
unnamed: C333.2, R349.1
unnamed: C334.2, R350.1
unnamed: C335.2, R351.1
unnamed: C336.2, R352.1
unnamed: C317.1, R317.2, U301.3 (+)
unnamed: C301.1, R309.2, U301.2 (-)
unnamed: C337.1, R345.2, U301.5 (+)
unnamed: C321.1, R337.2, U301.6 (-)
unnamed: C339.1, R347.2, U301.10 (+)
unnamed: C323.1, R339.2, U301.9 (-)
unnamed: C318.1, R318.2, U301.12 (+)
unnamed: C302.1, R310.2, U301.13 (-)
unnamed: C319.1, R319.2, U302.3 (+)
unnamed: C303.1, R311.2, U302.2 (-)
unnamed: C338.1, R346.2, U302.5 (+)
unnamed: C322.1, R338.2, U302.6 (-)
unnamed: C340.1, R348.2, U302.10 (+)
unnamed: C324.1, R340.2, U302.9 (-)
unnamed: C320.1, R320.2, U302.12 (+)
unnamed: C304.1, R312.2, U302.13 (-)

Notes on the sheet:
As configured: Analog Input (from DAC) = 4 V_{PP} Gain = 0.747; f_{-3 dB} = 53kHz; Output = 2 V_{RMS}
DECOUPLING
AC-COUPLED DAC OUTPUT BUFFER

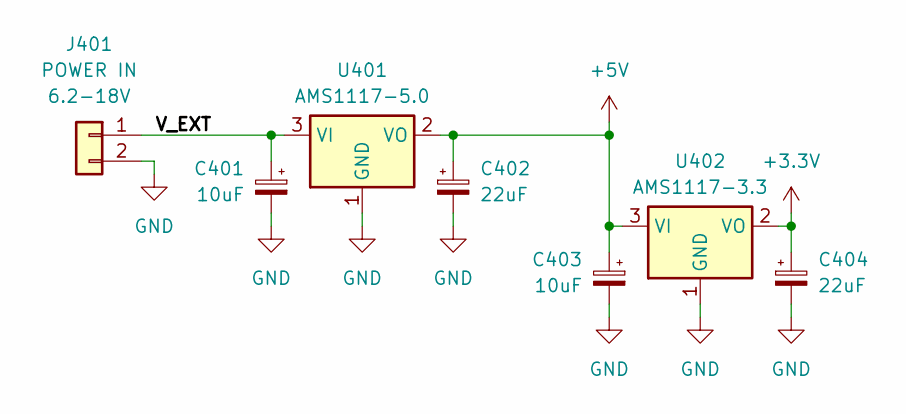
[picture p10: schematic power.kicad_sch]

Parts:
C401, C403: 10uF; CP_Elec_5x5.3
C402, C404: 22uF; CP_Elec_5x5.3
J401: POWER IN; Samtec_HPM-02-01-x-S_Straight_1x02_Pitch5.08mm
U401: AMS1117-5.0; SOT-223-3_TabPin2
U402: AMS1117-3.3; SOT-223-3_TabPin2

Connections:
+3.3V: C404.1, U402.2 (VO); also elsewhere on the board
+5V: C402.1, C403.1, U401.2 (VO), U402.3 (VI); also elsewhere on the board
/Power/V_EXT: C401.1, J401.1, U401.3 (VI)
GND: C401.2, C402.2, C403.2, C404.2, J401.2, U401.1 (GND), U402.1 (GND); also elsewhere on the board

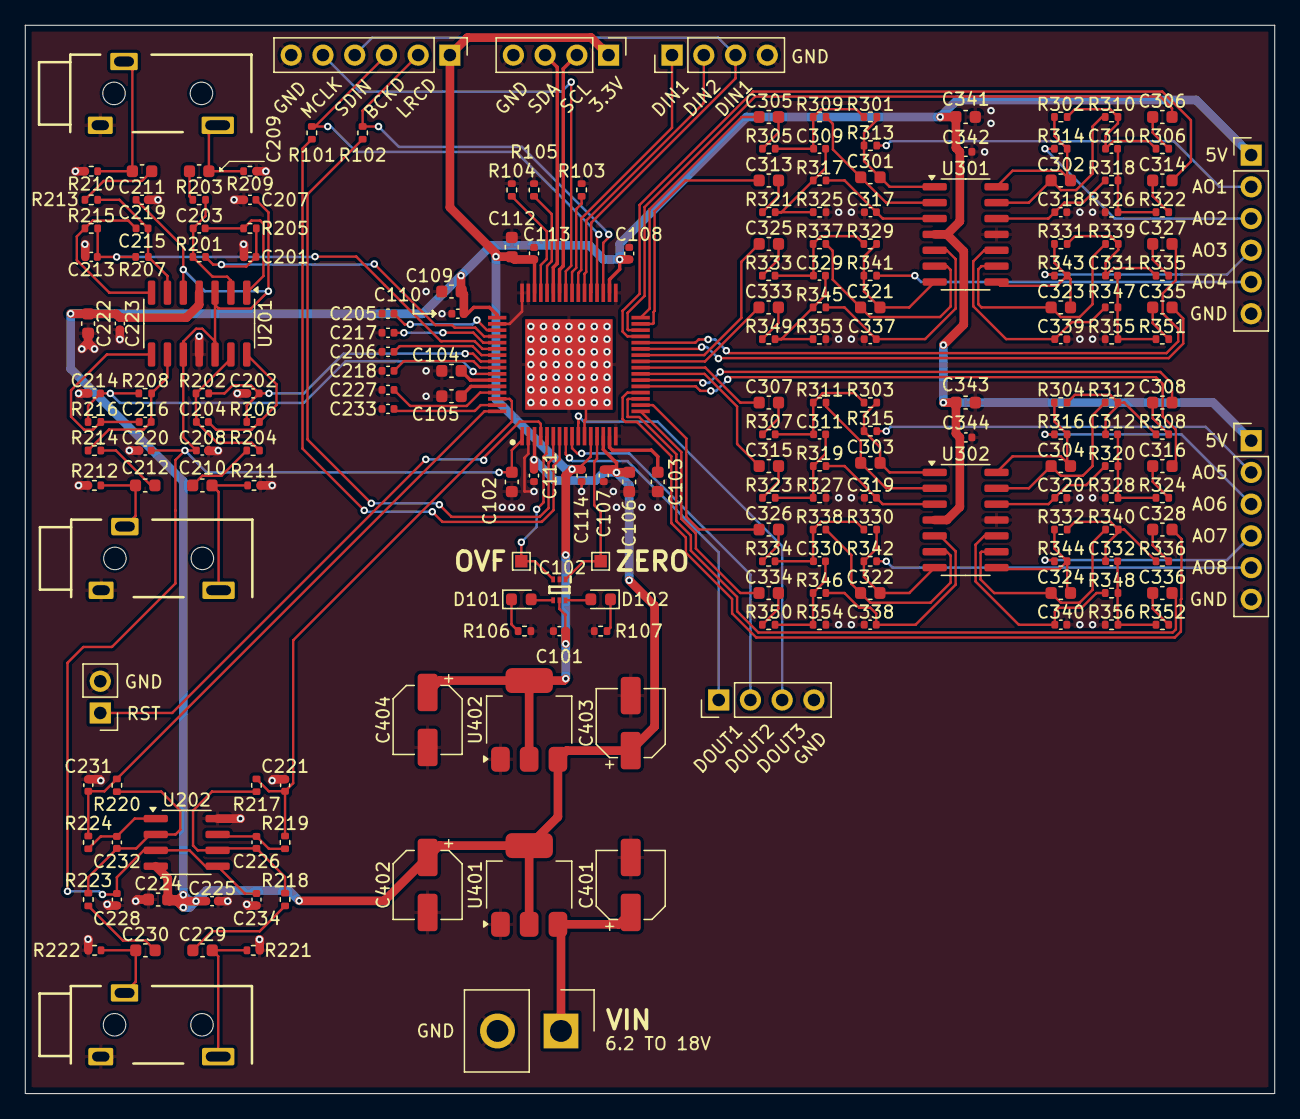
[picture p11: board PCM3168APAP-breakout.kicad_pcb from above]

Board: 4 copper layers, 100.0 x 85.5 mm, 206 parts (0 on the bottom side), 147 nets.

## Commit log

2026-01-13 schematic finished
    [PCM3168APAP-breakout.kicad_pcb, PCM3168APAP-breakout.kicad_sch, ain.kicad_sch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]
2026-01-13 schematic formatting
    [PCM3168APAP-breakout.kicad_sch]
2026-01-13 added current schematic pdf
2026-01-14 Cleaned up schematic
    [PCM3168APAP-breakout.kicad_pcb, PCM3168APAP-breakout.kicad_sch, ain.kicad_sch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]
2026-01-15 finished routin, updated schematic, added PDF
    [PCM3168APAP-breakout.kicad_pcb, ain.kicad_sch]
2026-01-15 finish routing, fix schematic, add images and PDF
